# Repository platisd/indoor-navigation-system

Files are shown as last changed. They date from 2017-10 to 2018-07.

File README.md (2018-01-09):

# Indoor Navigation System  

[WIP] An indoor navigation system that guides you to the desk of your colleagues.

## What?
INS is a navigation system that utilizes a fleet of portable embedded devices, which can be located, to guide its user towards the desk of an employee or a colleague. The main scenario begins by searching for an employee on a mobile client. Then the system provides information regarding the whereabouts of the said employee's desk as well as navigational instructions on how to reach it.

The system does not intend to monitor individuals, but merely broadcast their currently designated workspace. The tracking nodes are not meant to be constantly carried along, but placed on the desk where someone is working on and forgotten until their owner changes desk.

## Why?
Medium and large organizations involve office settings where employees are spread out throughout different floors. It is typically difficult to locate personnel with whom there is infrequent physical collaboration. The challenge becomes even greater when employees either do not possess a dedicated work-area or tend to move between locations. The main advantage of INS is that it provides dynamic updates in case the position of an employee's workspace changes, voiding the need for any manual action from  the employee's side.

What is possibly more important is the technology developed within this context, can be easily reused in different occasions, such as in IoT and indoor positioning applications.

## How?
A fleet of portable devices, transmit the signal strength (RSSI) of their surrounding WiFi access points (AP) to a central server. Since the exact location of the various APs is known, we can utilize the provided data to pinpoint the nodes within the building. Finally, a user can fetch the calculated location from the server using a mobile client.

INS is a distributed system composed of the following layers that communicate via HTTP requests:
* [Node](/ins-node)
  * A portable device that transmits the signal strengths it detects. It is comprised of a WiFi Module that handles the connectivity and a Power Module that determines when the node should go to sleep to minimize its power consumption.
* [Server](/server)
  * A REST server that receives the RSSI signals, calculates the location of each node and supplies the information to the interested parties.
* [Client](/ins-app)
  * A mobile client that visualizes the location of the inquired employee and guides its user towards that location.

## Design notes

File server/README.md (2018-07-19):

# INS Server
The INS server provides a backend RESTful service for INS-node and front-end web or mobile applications.

## API
* Send RSSI value to INS server (INS node)

  INS-nodes are required to send RSSI readings per wifi AP's mac address to INS-service. In a bid to have accurate readings and handle outliers, the INS-server supports sending multiple data points from INS-nodes. A minimum of 1 data point and maximum of 10 data points can be sent in one http request, while unlimited number of requests can be used in sending readings.

  * HTTP Method - `POST`
  * Request Url -  `/set_rssi/:device_id/:mac_addr1/:rssi1/:mac_addr2?/:rssi2?/:mac_addr3?/:rssi3? ... /:mac_addr10?/:rssi10/?`
  * Response - `{result:success}` or `{result:error}`

    #### Examples
  * INS-node with device id 1000 sends a one-time RSSI reading for MAC addresses 23:43:3d:3e:5e:f5 and  5a:4e:44:ff:5a:6e.

    `http://localhost:9080/set_rssi/1000/23:43:3d:3e:5e:f5/12.323/5a:4e:44:ff:5a:6e/44.3434`

  * INS-node with device id 5239 sends multiple RSSI readings from MAC addresses 23:43:3d:3e:5e:f5, `5a:4e:44:ff:5a:6e with different requests at different times.

    `http://localhost:9080/set_rssi/5239/23:43:3d:3e:5e:f5/13/5a:4e:44:ff:5a:6e/40`
    `http://localhost:9080/set_rssi/5239/23:43:3d:3e:5e:f5/11.3/5a:4e:44:ff:5a:6e/44.3`
    `http://localhost:9080/set_rssi/5239/23:43:3d:3e:5e:f5/15.6/5a:4e:44:ff:5a:6e/44.4`

* Trigger position calculation for device.

  Since INS-service supports data submission in batches, calculation of the INS-node position from RSSI readings is only done when the device prompts the server.
  * HTTP Method - `POST`
  * Request url - `/resolve_pos/:device_id`
  * Response - `{result:success}` or `{result:error}`

    #### Example
  * INS-node with device id 5239 triggers device position computation after sending several RSSI readings.

    `http://localhost:9080/resolve_pos/5239`

* Clear stored RSSI data for a device.

  In a scenario when an INS-node is moved from one place to the other, it becomes needed to promt the server to clear all previously stored data readings which automatically becomes invalid due to the move.
  * HTTP Method - 'POST'
  * Request url - `/reset_pos/:device_id`
  * Response - `{result:success}` or `{result:error}`

    #### Example

  * INS-node with device id '3331' resets its position.

    `http://localhost:5300/reset_pos/3331`

* Retrieve employee position (Frontend).

  This is for user facing applications interested in fetching employee's position.
  * HTTP Method - `GET`
  * Request Url - `/get_employee_pos/:employee_id`
  * Response - `{employee_id:<id>, pos_x:<val>, pos_y:<val>, pos_z:<val>}`

    #### Example
  * Get position of employee with id = 8923

    `http://localhost:5300/get_employee_pos/8923`

* Retrieve device position (Frontend).

  This is for user facing applications interested in fetching position of an INS-node devicce.
  * HTTP Method - `GET`
  * Request Url - `/get_device_pos/:device_id`
  * Response - `{device_id:<id>, pos_x:<val>, pos_y:<val>, pos_z:<val>}`

    #### Example

  * Get position of device with id = 2020

    `http://localhost:5300/get_device_pos/2020`

## Dependencies
* [Pistache](http://pistache.io/)
* [Sqlite3](https://www.sqlite.org/)
* [spdlog](https://github.com/gabime/spdlog)

### How To Fetch Dependencies
#### Ubuntu
* Install SQLite3
    * `sudo apt-get install sqlite3 libsqlite3-dev -y`
* Install Pistache
    * `git clone https://github.com/oktal/pistache.git`
    * `cd pistache`
    * `mkdir build && cd build`
    * `cmake -G "Unix Makefiles" -DCMAKE_BUILD_TYPE=Release ..`
    * `make`
    * `sudo make install`

## Build & Run Backend Server
Ensure all needed libraries are installed.
* `cd server`
* `mkdir build`
* `cd build`
* `cmake ..`
* `make`
* To run use `./ins_server [port]`

## Testing
This component is tested using [GoogleTest](https://github.com/google/googletest/tree/master/googletest) and [GoogleMock](https://github.com/google/googletest/tree/master/googlemock) which are C++ testing and mocking frameworks.

The repository contains a [include/](include/) and [src/](src/) directories where the user is expected to maintain their production code and the [test/](test/) directory where the respective unit test and mocks have to be placed.

### How to run tests
* Build and run unit tests
  * `build_and_run_ut.sh`
* Build and run unit tests, cleaning the build folder
  * `build_and_run_ut.sh --clean`

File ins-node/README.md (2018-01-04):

# INS-node
The INS-node is the device that will allow us to pinpoint the location of our colleagues' desks.

## Setup your IDE
Follow the instructions found [here](https://wiki.wemos.cc/tutorials:get_started:get_started_in_arduino#using_git_version) to setup your Arduino IDE and enable it to compile and upload sketches for Wemos Mini D1.

To be able to compile for the ATtiny, please follow the instructions [here](https://github.com/SpenceKonde/ATTinyCore/blob/master/Installation.md).

## Power Controller :left_right_arrow: WiFi Module interaction
The Power Controller MCU is in charge of managing when the WiFi module is to be turned on. That being said, the WiFi module occasionally has some saying on what needs to be done.

There are two signals connecting the two components which additionally happen to be UART-capable. On the Power Controller these are `PB0` as `TX` and `PB1` as RX. On the WiFi module the standard `RX` and `TX` pins are utilized. Currently the two modules interact through sending signals as short (few microseconds) pulses.

The following table describes the protocol in the different states.

| Power Controller state | Source | Destination | Description |
| :----:|:----:|:----:|:----:|
| `SLEEP_WIFI_ON` | Power Controller | WiFi Module  | Notifies WiFi Module to shutdown, transits to `PREPARE_SHUTDOWN` state where it will turn off after `WIFI_PREPARE_SHUTDOWN_DURATION`. |
| `SLEEP_WIFI_ON` |  WiFi Module | Power Controller | Notifies Power Controller that it wants to shutdown and Power Controller transits to `PREPARE_SHUTDOWN` state where it will turn off after `WIFI_PREPARE_SHUTDOWN_DURATION`. |
| `PREPARE_SHUTDOWN` |  WiFi Module | Power Controller | Notifies Power Controller to prevent shutdown and go back to `SLEEP_WIFI_ON` state. |

## Testing
To test the INS-node code we base our work on the [Smartcar-gmock](https://github.com/platisd/smartcar-gmock) framework.

It is based on [GoogleTest](https://github.com/google/googletest/tree/master/googletest) and [GoogleMock](https://github.com/google/googletest/tree/master/googlemock) which are some easy-to-use C++ testing and mocking frameworks. It builds upon the [Arduino-Mock](https://github.com/ikeyasu/arduino-mock) project by Anders Arnholm and Yasuki Ikeuchi.

The repository contains a [src/](src/) directory where the user is expected to maintain their production code and the [test/ut/](test/ut/) directory where the respective unit tests (\*.cc files) have to be placed.

The main challenge with testing this is that the Arduino library was not created with testability in mind. There are already plenty of mocks, however they are not enough to cover the whole API. In case more mocks **need** to be added, we can use our local [fork](https://github.com/platisd/arduino-mock) to do so. Alternatively, functions, registers and variables should be stubbed when their mocking is not crucial for the testing process.

### How to run tests
* Build and run unit tests
  * `build_and_run_ut.sh`
* Build and run unit tests, cleaning the build folder
  * `build_and_run_ut.sh --clean`

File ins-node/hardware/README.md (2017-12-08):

# INS-node hardware
INS-node board schematics and layout designed with Eagle CAD.

## Features
* UART connection between power controller MCU and WiFi module
* N-channel MOSFETs to control the power
* 1 LED for power controller MCU
* 1 LED for WiFi module
* Decoupling capacitors
* Reset button for power controller MCU
* Drawing area for node id
* Mounting holes for M3 screws

## 2D board renders
* Top view

ins board TOP
* Bottom view

ins board BOTTOM

## List of materials
* Wemos D1 Mini
* ATtiny85
* 3 x AAA battery holders
* 2 x 2N7000 N-channel MOSFET
* 2 x 220 Ohm resistors
* 2 x 4.7 KOhm resistors
* 0.1 uF capacitor
* 2 x 5mm LED
* SPST tactile switch

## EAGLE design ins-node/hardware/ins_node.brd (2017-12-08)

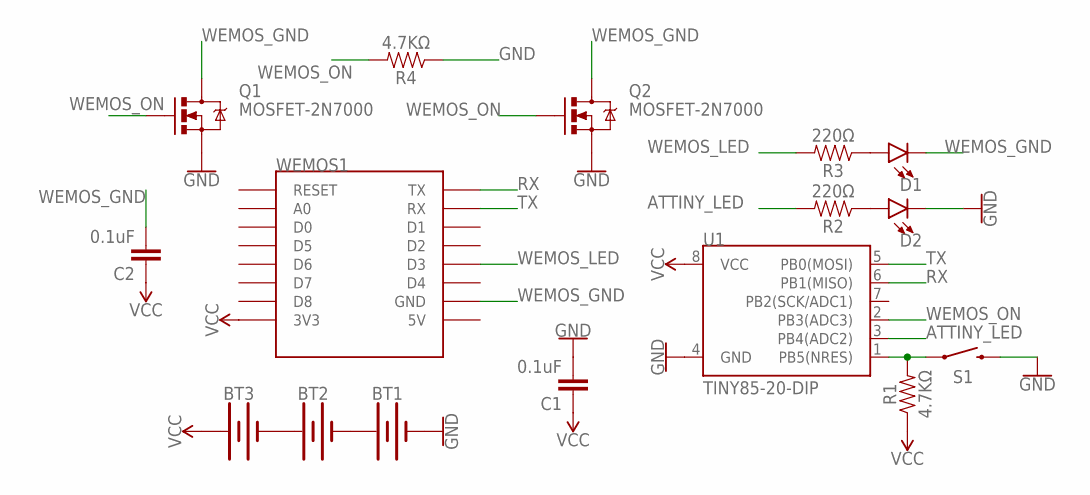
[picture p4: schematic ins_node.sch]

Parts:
BT1, BT2, BT3: BATTERY-AAA
C1, C2: 0.1uF; CAP-PTH-SMALL-KIT
D1, D2: LED5MM-KIT; LED_5MM-KIT
Q1, Q2: MOSFET-2N7000; TO-92
R1, R4: 4.7KΩ; AXIAL-0.3
R2, R3: 220Ω; AXIAL-0.3
S1: MOMENTARY-SWITCH-SPST-PTH-6.0MM; TACTILE_SWITCH_PTH_6.0MM
U1: TINY85-20-DIP; DIP08_MCU
WEMOS1: WEMOS-D1-MINI

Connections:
ATTINY_LED: R2.P$2 (2), U1.3 (PB4(ADC2))
GND: BT1.GND@1 (-), C1.2, D2.K (C), Q1.1 (S), Q2.1 (S), R4.P$1 (1), S1.3 (2), U1.4 (GND)
unnamed: BT1.PWR@1 (+), BT2.GND@1 (-)
unnamed: R1.P$2 (2), S1.1, U1.1 (PB5(NRES))
unnamed: D1.A, R3.P$1 (1)
unnamed: D2.A, R2.P$1 (1)
unnamed: BT2.PWR@1 (+), BT3.GND@1 (-)
RX: U1.6 (PB1(MISO)), WEMOS1.TX
TX: U1.5 (PB0(MOSI)), WEMOS1.RX
VCC: BT3.PWR@1 (+), C1.1, C2.1, R1.P$1 (1), U1.8 (VCC), WEMOS1.3V3
WEMOS_GND: C2.2, D1.K (C), Q1.3 (D), Q2.3 (D), WEMOS1.GND
WEMOS_LED: R3.P$2 (2), WEMOS1.D3
WEMOS_ON: Q1.2 (G), Q2.2 (G), R4.P$2 (2), U1.2 (PB3(ADC3))

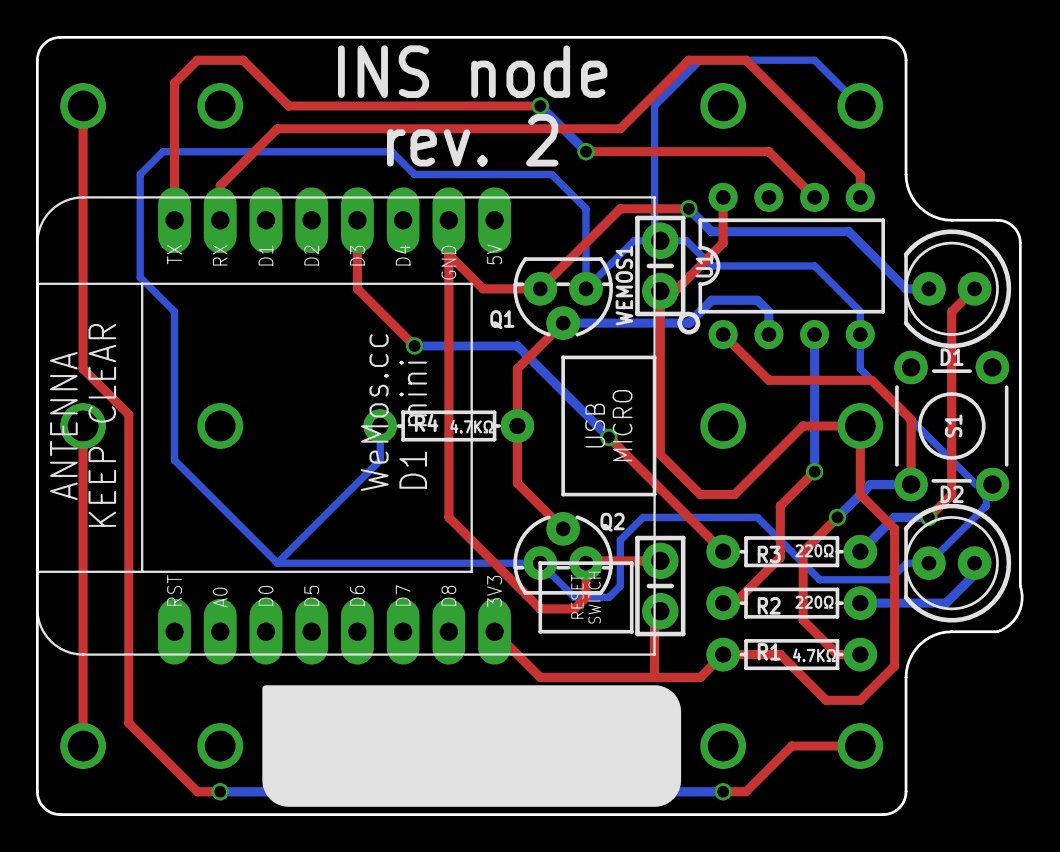
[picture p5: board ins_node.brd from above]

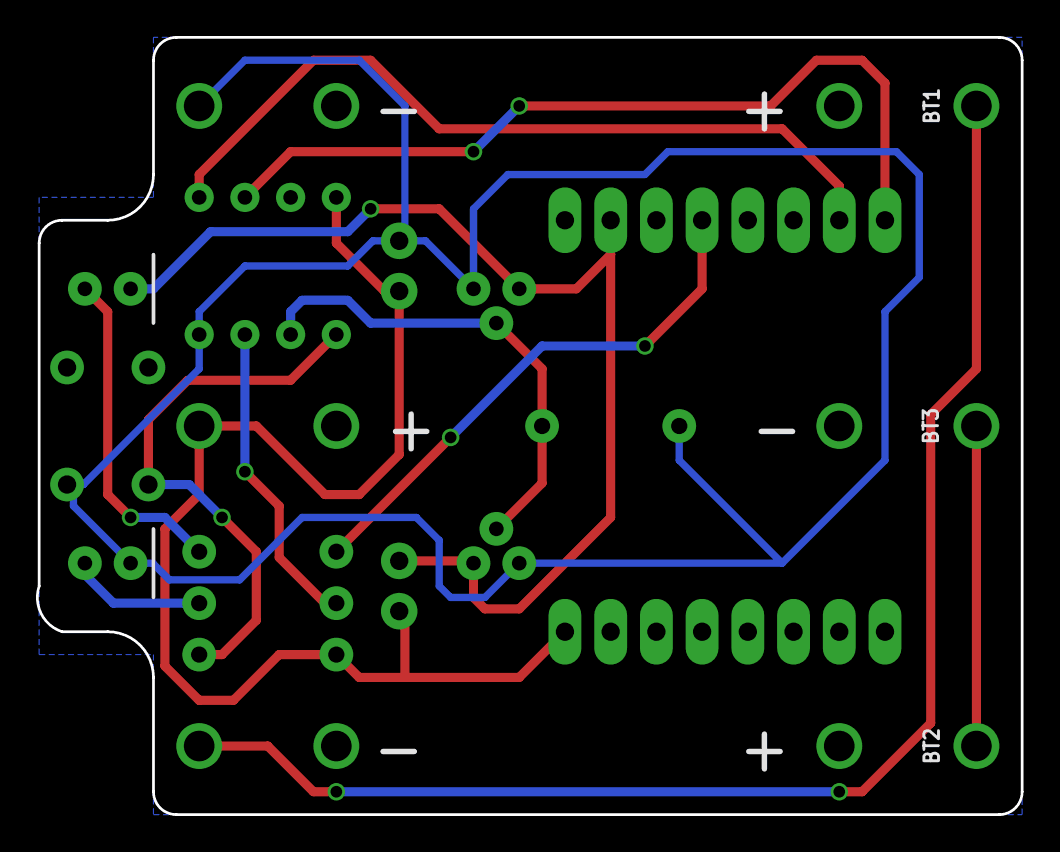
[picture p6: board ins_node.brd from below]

Board: 2 copper layers, 54.7 x 43.2 mm, 16 parts (3 on the bottom side), 13 nets.

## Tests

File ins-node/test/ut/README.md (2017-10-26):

## Unit test code directory
Place your unit tests, that you want to test and/or run on the INS node here as *.cc files.

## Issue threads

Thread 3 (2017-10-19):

Missing CI

platisd, 2017-10-19:
As a developer or tester, I would like the project to be built and the test cases to be ran after every commit so to figure out if my changes are making the system fail.

DoD:
* Decide on which CI (e.g. [Travis](https://travis-ci.org/))  is most suitable.
* Set up CI machinery that will build the current components (if possible) after every commit.
* Provide access to the CI machinery to rest of the project members.

Closed 2017-10-19.

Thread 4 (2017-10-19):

Backend Impl - REST Server

platisd, 2017-10-19:
As a developer, I would like to have REST server that can handle HTTP POST/GET requests, so that devices & frontend app can communicate with the server.

platisd, 2017-10-19:
Is this done @samup4web ?

samup4web, 2017-10-19:
This issue and the database impl issue are somehow in the same boat. More work to be done as new related tasks unfolds.

samup4web, 2017-10-20:
Fixed in [commit](https://github.com/platisd/indoor-navigation-system/commit/8e1333d574c81e35b327888606187d7dc6828c4e)

Closed 2017-10-20.

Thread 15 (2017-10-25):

Missing test infrastructure - server

platisd, 2017-10-25:
As a CI machine I would like to be able to have the infrastructure in place which will enable me to run unit tests.

DoD:
* `run_ut.sh` script inside `server` directory which builds and runs a sample unit test.

platisd, 2017-11-01:
This is done right? If so, move it to "Ready for internal acceptance" in the project board! :)

Closed 2017-10-29.

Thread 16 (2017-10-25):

Missing test infrastructure - ins-node

platisd, 2017-10-25:
As a CI machine I would like to be able to have the infrastructure in place which will enable me to run unit tests.

DoD:
* `build_and_run_ut.sh` script inside `ins-node` directory which builds and runs a sample unit test.

Protip:
* Follow [smartcar-gmock](https://github.com/platisd/smartcar-gmock) structure for testing and mocking arduino.

samup4web, 2017-10-27:
So, after preparing my commit for test infrastructure for the server. I saw [this](https://github.com/platisd/indoor-navigation-system/blob/323b52b1a12611e5bdb707e32dee58535e1602ca/ins-node/test/arduino_mock/CMakeLists.txt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) in your commit. That is super new to me. I guess I wouldn't need a copy of gtest/gmock with your approach. I will fix the feature branch before making a pull request. Cheers!

platisd, 2017-10-27:
You don't really *have* to follow that approach, but if you think it makes sense sure, go for it! :+1:  :smiley:

samup4web, 2017-10-27:
Yeah, I think it's a cool approach 😄

Closed 2017-10-26.

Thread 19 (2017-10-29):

Missing hardware prototype

platisd, 2017-10-29:
As an INS-node I want become materialized so to stop being a figment of imagination and speculation.

DoD:
* Board layout and schematics designed in [Eagle CAD](https://www.autodesk.com/products/eagle/overview)
* ~~[Fritzing](http://fritzing.org/home/) diagram added in [README.md](https://github.com/platisd/indoor-navigation-system/blob/master/ins-node/README.md)~~

platisd, 2017-10-29:
@samup4web @lexious89 I was thinking about the optimum hardware setup for the beginning and concluded on a [Wemos D1 Mini](https://wiki.wemos.cc/products:d1:d1_mini), **instead** of an [ESP-01](https://4tronix.co.uk/store/resources/image/18/c2/2.jpg), Attiny25 (or 85) combo. This means that the total architecture will change a little bit as to where the main business logic is contained.

According to the old setup:
* ESP-01 was operated in AT-mode, meaning that we send commands to it via UART.
* Attiny parses the results and handles power management.

According to the new setup:
* We program the ESP8266 on the Wemos D1 Mini directly.
* Attiny handles power management.

Advantages :vs: disadvantages of the new approach:
* Easier and faster to develop/modify the main business logic since the Wemos can be programmed over USB with the Arduino IDE. :white_check_mark:
* Can practically use any other ESP8266 USB development module like the one @lexious89 has. :white_check_mark:
* Slightly more expensive. (ESP-01 costs ~1.6$ while Wemos D1 Mini costs ~2.6$) :x:
* Slightly larger. :white_check_mark:
* Faster and more versatile setup since we do not rely on already made AT-commands to access the ESP8266 but we program it directly. :white_check_mark:
* Simpler and fewer hardware connections on the PCB from our side, meaning less risk. :white_check_mark:

Does it sound good? :smiley:

PS. Also thinking of a knowledge sharing workshop on PCB design where I can go over how to design the board if you are interested in it!

samup4web, 2017-10-29:
Sounds like a good idea. I guess the cost impact is quite marginal, and for the size, as long as we can package it in something nice then I see no problem.

The PCB design knowledge sharing is a great idea!.

platisd, 2017-10-29:
I have scratched out the creation of a Fritzing diagram as it will be redundant work at this point.

Closed 2017-10-30.

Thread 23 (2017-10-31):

Missing initial implementation of power controller

platisd, 2017-10-31:
As an INS node, I would like my power controller to turn off the Wifi module when it is not needed and stay in deep sleep as much as possible so to preserve precious battery life.

DoD:
* Wifi module gets turned on every ~1 minute.
* MCU stays in deep sleep as much as possible.
* State machine with (at least) the following states:
  * `SLEEP_WIFI_OFF` (the wifi module is off, while power controller is in deep sleep and can be woken up by a watchdog timer)
  * `SLEEP_WIFI_ON` (the wifi module is on, while power controller is in deep sleep and can be woken up by a watchdog timer or an external interrupt).
  * `PREPARE_SHUTDOWN` (the power controller warns the Wifi module it is time to shutdown and then it goes to deep sleep for a limited period. The Wifi module can ask to postpone shutdown if it is not ready to)

Closed 2017-11-17.

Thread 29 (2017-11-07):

Apply corrections to rev. 0 board

platisd, 2017-11-07:
As an INS I want to work as intended by my creators so to make them happy.

**HW rev. 0** has the following problems:
* Batteries slightly too close to the WiFi Module, should be moved couple of millimeters to the sides.
* Understand why WiFi module receives too low voltage and implement a solution.

DoD:
Above problems are fixed and new boards are ordered.

platisd, 2017-11-09:
These are my current findings in regards to this problem:
* I could not get the Wemos D1 mini to power up directly from 2 AAA batteries (or the equivalent voltage) in any consistent nor reliable manner. I could however get it to power up **directly** from **3 batteries** connected to the 5V pin or the 3.3V pin.
* Using **two** 2N7000 MOSFETs to handle the current (it won't work with just the one we currently have!) I was able to power it up reliably with voltages from 4.0V to 4.5V connected to the 3.3V pin. This is probably not a very good idea, but seems to work. Now whether this will destroy the ESP chip at some point is a different question. :stuck_out_tongue:
* Two MOSFETs will be also able to drive 5V to the 5V pin and power the WeMos up reliably.
* Three MOSFETs were also able to drive the Wemos with 4.5V connected to the 5V pin. However there seemed to be problems when I lowered the voltage to around 4V.
* I was reading contradicting reviews on the Wemos power consumption while in deep sleep (i.e. in the occasion we'd decide not to use a power controller chip). Some were very optimistic (e.g. 150uA in deep sleep which would allow the batteries to last for at least a couple of months) while others gave a pretty bad picture (e.g. 20mA). I did not have time to make my own experiments, so this might worth investigating more.

So, overall there seem to be various options available on how to power the WeMoS up. The overall problem is choosing the appropriate power source at a voltage that is as close to the specs as possible AND at the same time will keep being able to power the WeMos even if the voltage falls as time passes (and also cheap).

My best suggestion is 3 AAA batteries wired up to the 3.3V pin driven by 2 2N7000 MOSFETs. At full battery power, the voltage that actually reaches the chip is 4V. According to the specs, the maximum voltage is 3.6 voltage. We seem to be over it by 0.4V in other words, but since it seems to work and the plan is to keep the Wemos turned off for most of the time, I suggest that we go for that. It is a risk, but I honestly cannot think of a better solution that will not cost us a lot and will have other problems (I am looking at you Lithum batteries).

Let's make a decision tomorrow and order the new boards by tomorrow night!

Closed 2017-11-13.

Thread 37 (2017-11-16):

Have the CI build the ins-node firmware (Power Controller)

platisd, 2017-11-16:
As a developer or an integrator I want to be certain that what I wrote will compile in all setups so to avoid having non-working software committed even though the until tests passed.

DoD:
* The CI machine compiles the firmware for the appropriate microcontroller before/after running the unit tests.

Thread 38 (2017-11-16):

Have the CI build the Wifi Module firmware

platisd, 2017-11-16:
As a developer or an integrator I want to be certain that what I wrote will compile in all setups so to avoid having non-working software committed even though the until tests passed.

DoD:
* The CI machine compiles the firmware for the appropriate microcontroller before/after running the unit tests.

platisd, 2018-01-03:
Building the firmware for the ESP8266 as well as the power controller (see #37) seems to require downloading the Arduino IDE as well as the necessary additional libraries and SDKs. This will make the whole build much slower, especially in the case of the ESP8266.

Currently, the build is a bit over 20 minutes so we should consider whether we want these builds to take place.

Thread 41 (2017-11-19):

Determine the cause of Wemos external LED malfunction

platisd, 2017-11-19:
The LED connected to the WiFi module is misbehaving (i.e is constantly turned on) regardless of the WiFi Module's pin output.

DoD:
* Determine the cause of this defect (it is hardware/electrical related)
* Apply corrective action (removing the LED completely is not a bad option)

platisd, 2017-12-05:
This is probably related to #65

platisd, 2017-12-22:
I am almost sure the problem stems from the fact that we are using software for a newer hardware version (i.e. R2 and R3) than we actually have (R1). It looks like the mapping of Arduino pin numbers to ESP8266 pins has changed between the versions! For example, for R1 hardware, pin D4 in code is actually D2 on the board!

I shall investigate this further soon to determine the cause of this defect with greater certainty, regardless of whether we maintain the specific LED on the board or not.

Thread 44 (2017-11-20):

Wifi module gets a list of RSSI values from different AP's for specified SSID

platisd, 2017-11-20:
As a WiFi module I want to be able to retrieve the RSSI values from the surrounding AP's of a specified SSID so to be able to send them to the server.

DoD:
* The WiFi module is able to fetch the SSID's of a specified SSID.
  * To verify this they can be printed out for the time being.
* Unit tests that cover the new functionality.
  * A lot of mocking probably has to be done. Keep in mind that the current mocks don't cover Arduino's `String` class type.

platisd, 2017-11-20:
@lexious89 can you please add the relevant code you had demonstrated for us?

Closed 2017-12-05.

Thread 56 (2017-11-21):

Stabilize pseudo random rssi levels by filtering out shadowing and multipath noise.

lexious89, 2017-11-21:
## Description
Due to random effects in the environment, rssi levels taken even within small intervals appear random and noisy. In order to compute a stable position, we need to filter out the randomness due to shadowing and mulitath and only have just path loss. One way to do this is for eg: moving averaging.
## Definition of Done
Compute a single value that represents the signal level at a single position.

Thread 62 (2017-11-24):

Refactor: Change RSSI datatype

samup4web, 2017-11-24:
## Description
Since it is confirmed that `rssi` representation is indeed `int32_t` [(link),](https://github.com/esp8266/Arduino/blob/d7044eceab4d4453e4d73ac49dcbbc8b8d0c9eb1/doc/esp8266wifi/scan-class.rst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) as a developer, I want the correct datatype used for all `rssi` variables.

## Definition of Done
Correct datatype is used for RSSI variables.

Closed 2017-12-05.

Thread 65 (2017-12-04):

PB0 (TX) pin emits negative voltage

platisd, 2017-12-04:
## Description
PB0 has been measured to emit negative voltage (when it should be steadily at 0V with the current firmware) which results in a weird ~1.0V value being supplied at the wifi module even when it is off.

A workaround for this is to bend (not connect) the RX pin of the WiFi module.

## Definition of Done
Root cause of this strange behavior is identified and a fix is issued.

Closed 2017-12-08.

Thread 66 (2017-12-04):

Wrong pin used for turning Wifi module ON

platisd, 2017-12-04:
## Description
The power controller uses the PB2 for turning the WiFi module ON, while according to the schematics the PB3 pin should be used instead.

## Definition of Done
PB3 pin is used to turn the WiFi module on in the power controller firmware.

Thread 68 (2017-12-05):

Server core-dumps after ~16 minutes of operation

platisd, 2017-12-05:
## Description
The `ins_server` core-dumps after approximately 16 minutes of operation, regardless of whether it is handling incoming data or not. The defect was reproducible 100% of the times.

### Ways to reproduce
Have `ins_server` executing for long amounts of time.

### Related logs
> terminate called after throwing an instance of 'std::runtime_error'
>   what():  No route to host
> Aborted (core dumped)

## Definition of Done
The `ins_server` can run for indefinite amounts of time.

samup4web, 2017-12-05:
@platisd hmm, what is your setup like?
I tried running the ins_server on my machine and it runs for over 1 hour, and also accepted request thereafter. See the time-stamp prints in the screenshot below.
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

I will investigate further...

samup4web, 2017-12-05:
I still have the server running, I will see how long before I reproduce the problem.

platisd, 2017-12-05:
How did it go? Otherwise it must be some local weird error, since I could consistently reproduce it.

samup4web, 2017-12-05:
Still running at 19:38 ...

platisd, 2017-12-05:
Weird... Let's close this for now and I will open it again if I have a different angle on it.

samup4web, 2017-12-05:
@lexious89 can you try to run the server on your box and let's see if you can reproduce the problem.

samup4web, 2017-12-09:
I manage to reproduce this issue. I will be investigating further...

platisd, 2017-12-09:
Interesting, keep us posted! :+1:

samup4web, 2017-12-09:
Strangely enough, I am on my second attempt to reproduce the problem after the first crash with no success. Will be testing on both my ubuntu box and rasberrypi.

samup4web, 2017-12-09:
On a side note, @platisd are you on slack?

platisd, 2017-12-09:
I sure am! 😛

Send invite to my work mail if you're making a channel

samup4web, 2017-12-09:
Done.

samup4web, 2017-12-09:
OK, couldn't get it to crash. So, am making a new run on rasberrypi now.
* ins service start time - [2017-12-09 17:36:55.200]
* ins_node start time - [2017-12-09 18:16:52.178]
* current time - [2017-12-09 18:35:01.948]
This will be running all night, so fingers crossed.

platisd, 2017-12-09:
What is your setup like? Are you using the wifi_module.ino without letting it sleep?

samup4web, 2017-12-09:
Yes, modified wifi_module to not sleep and send data continuously with `delay(20000);`.

samup4web, 2017-12-10:
Strange that INS service has been running all night/day and still running (on rasberrypi)
* current time - `[2017-12-10 14:01:14.282]`

I had to press reset button on ins_node this morning because it wasn't sending out data. I guess due to network connection.

platisd, 2017-12-10:
I will also try to debug this when I find the time. Any suggestions on where to add extra logs?

samup4web, 2017-12-10:
Okay, great! As for extra logs, none that I can think of now.

samup4web, 2018-01-20:
Closing this issue since we haven't observed this issue lately. This can be re-opened again if problem reoccur

platisd, 2018-01-20:
I agree. That being said, I think it could make sense to invest in making a Docker image to make sure everyone is running things in the same environment. :+1:

samup4web, 2018-01-20:
Haha, nice idea. Taking it to another level :smile_cat:

Closed 2018-01-20.

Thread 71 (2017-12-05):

Add pull down resistors to MOSFETs so to ensure a clean trigger signal

platisd, 2017-12-05:
## Description
As a Wifi module I want to be turned on only when the Power Controller sees it fit and not accidentally by rogue static voltages applied on the trigger pins of the MOSFETs.

## Definition of Done
* Pull down resistor added
* BOM updated
* Board renders updated

Closed 2017-12-08.

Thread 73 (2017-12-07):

Android application setup missing

platisd, 2017-12-07:
## Description
As an INS Android app developer I want to have a sample Hello World application integrated into the CI build and tested, so to be able to seamlessly create awesome things with it.

## Definition of Done
* Hello World android application
* Built and tested by the CI machine
* Coverage reports on codecov.

Closed 2017-12-30.

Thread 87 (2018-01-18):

INS node position resolution missing

platisd, 2018-01-18:
## Description
As an INS node I should instruct the server to resolve my position after I am done transmitting the RSSI values. On how to do that, please refer to `Trigger position calculation for device` section of the [server/README.md](https://github.com/platisd/indoor-navigation-system/blob/dev/server/README.md).

## Definition of Done
* The `ins-node` [WiFi module](https://github.com/platisd/indoor-navigation-system/blob/dev/ins-node/src/wifi_module/wifi_module.ino) is able to trigger the position resolution interface of the server after successfully transmitting a batch of data.
* The added functionality is tested.

lexious89, 2018-04-13:
+ and in addition ask the server to resolve position some fixed period (say every minute) even if the device node does not request it.

platisd, 2018-04-13:
Do you mean to have a timer on the server? I think it's supposed to be stateless. What do you think @samup4web

lexious89, 2018-04-13:
Yes, it is stateless in relation to the ins nodes. But the server knows how long it has been running.
This is needed because if it is the first time the insnode is transmitting data and it happens to loose connection or something goes wrong so that the location table in ins_db is empty for that device, any front end get-position request will yield unpredictable results - a nan in the localization process, whilst in fact the data is available for localization.

platisd, 2018-04-13:
Sounds good to me

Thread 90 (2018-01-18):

C++ code has been committed without being static analyzed

platisd, 2018-01-18:
## Description
As an INS developer I do not want to have code that has not been approved by a static analysis tool committed to one of the main branches. Therefore, I would like to make sure that my code is verified by a static analysis tool before being allowed to merge.

A good relevant post to read can be found [here](https://legalizeadulthood.wordpress.com/2014/12/07/adding-static-analysis-to-your-c-github-repository/).

## Definition of Done
* A static analysis tool (e.g. `cppcheck`) is run by Travis and verifies the submitted code before allowing to merge
* Static analysis script is present in the c++ source folders, e.g. `server/run_static_analysis.sh`
* Current problems, discovered by static analysis tool, are addressed
* (Optional) Try to run the static analysis check in parallel with the rest of the build

samup4web, 2018-01-20:
Clang-tidy :+1:

platisd, 2018-01-20:
Up to the one who implements this! :smiley:

platisd, 2018-01-22:
@samup4web are you currently working on this? If so please move this to the appropriate column in the board otherwise unassign yourself so maybe new members can take it! 😄

samup4web, 2018-01-22:
Yes working on this, forgot to move it status.

lexious89, 2018-04-23:
Is this issue solved? @samup4web

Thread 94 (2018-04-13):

Create patch case to adapt project to a specific case

lexious89, 2018-04-13:
## Description
As the project is intended for indoor settings, different cases will require special configurations, graphics and resources in local config etc. You can either do this in code or by patching before building.
We want to create a simple patch for a specific case that anyone can modify to suite their own application.
## Definition of Done
Fulfill the above requirement by providing a patch script in the repository.

platisd, 2018-04-13:
Can you be more specific on what needs to be done? If I were to take up this story I wouldn't know what to do or where to start!

platisd, 2018-04-14:
I was thinking of this and I believe that you mean that we should refactor this so to be a platform and be able to satisfy different use cases. Right now the "platform" (i.e. purpose agnostic hardware and software) are tightly coupled with the "indoor navigation" use case.

I do agree that this should happen but it's a rather large task that should be broken down further and possibly some architectural changes should ensue!

lexious89, 2018-04-16:
Yes, I agree the description is quiet vague. I have updated the contents above. The platform is indeed for indoor cases alone. But different indoor settings will employ different wifi APs (mac address, rssi levels etc), and indoor maps, perhaps in the future, various ins node hw/sw-revisions. We can't anticipate all use cases. But it would be really helpful to be able to run a script to swap between various use cases (platform) and a generic patch script might be enough. This is what I meant.
I guess we could break it down into smaller series of tasks.

platisd, 2018-04-16:
OK I understand better now but still think it needs smaller tasks as well as some architectural discussion. The main problem is that some of the infrastructure and prerequisites for this are missing.

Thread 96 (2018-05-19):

Read and transmit temperature readings along with the RSSI data

platisd, 2018-05-19:
## Description
As an facilities manager I want to be able to see what is the temperature around each INS-node so to be able to adjust the heating or cooling accordingly.

## Definition of Done
* A readily available, cheap and small temperature sensor is selected
* The INS-node is able to measure the temperature
* The INS-node is able to transmit the measured temperature along with the RSSI readings

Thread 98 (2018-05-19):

INS app to fetch temperature data and visualize them

platisd, 2018-05-19:
## Description
As an facilities manager I want to be able to see what is the temperature around each INS-node so to be able to adjust the heating or cooling accordingly.

## Definition of Done
* INS app to fetch the temperature data for each node id from the server.
  * The POST request should be formulated as `http://localhost:9080/get_temperature/id` where `id` is an arbitrary identification number (integer) until #82 is implemented.
* The temperature is visualized with different colors over a map of the floor.
* Documentation is updated accordingly (if applicable).

platisd, 2018-05-19:
@Dionysios it goes without saying that you should feel free to add more details to this issue, as long as the scope doesn't stretch "too much" :stuck_out_tongue: .

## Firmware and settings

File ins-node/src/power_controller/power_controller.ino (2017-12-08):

#include <stdint.h>
#include <avr/sleep.h>
#include <avr/power.h>
#include <avr/wdt.h>
#include <avr/interrupt.h>

enum WatchDogTimeout {
  WDT_16ms = 0,
  WDT_32ms,
  WDT_64ms,
  WDT_128ms,
  WDT_250ms,
  WDT_500ms,
  WDT_1sec,
  WDT_2sec,
  WDT_4sec,
  WDT_8sec
};

enum PowerState {
  // The wifi module is off, while power controller is
  // in deep sleep and can be woken up by a watchdog timer.
  SLEEP_WIFI_OFF,
  // The wifi module is on, while power controller is in
  // deep sleep and can be woken up by a watchdog timer
  // or an external interrupt.
  SLEEP_WIFI_ON,
  // The power controller warns the Wifi module it is time
  // to shutdown and then it goes to deep sleep for a
  // limited period. The Wifi module can ask to postpone
  // shutdown if it is not ready yet.
  PREPARE_SHUTDOWN
};

const uint8_t TX_PIN = PB0;
const uint8_t RX_PIN = PB1;
const uint8_t WIFI_MODULE_PIN = PB3; // Controls the power to the Wifi module

WatchDogTimeout currentTimeout = WDT_8sec; // Current watchdog timeout

unsigned long timeWeHaveSlept = 0; // The total amount of time we have been asleep
volatile bool watchDogBarked = false; // Flag to determine the source of a wake up
bool watchDogEnabled = false;

const unsigned long WIFI_OFF_SLEEP_DURATION = 16000UL; // TO-DO: Change this to something larger
const unsigned long WIFI_ON_SLEEP_DURATION = 16000UL; // TO-DO: Change this to something larger
const unsigned long WIFI_PREPARE_SHUTDOWN_DURATION = 10000UL;

volatile bool signalFromWifiModule = false; // Flag to determine if WiFi module has signaled us

PowerState currentState = SLEEP_WIFI_OFF; // Current operational state

/**
   Change interrupt routine (e.g. when WiFi module signals us)
*/
ISR (PCINT0_vect) {
  // Only consider interrupts from the defined source and during the proper state(s)
  if ((currentState == SLEEP_WIFI_ON) && (digitalRead(RX_PIN) == HIGH)) {
    signalFromWifiModule = true;
  }
}

/**
  Watchdog interrupt routine to be triggered when watchdog times out.
*/
ISR(WDT_vect) {
  watchDogBarked = true;
  wdt_disable(); // Disable watchdog so it does not get automatically retriggered
}

/**
    Sets up watchdog to be triggered (once) after the specified time
    @param wdt  the watchdog timeout duration
*/
void triggerWatchDogIn(WatchDogTimeout wdt) {
  // Adopted from InsideGadgets (www.insidegadgets.com)
  byte timeoutVal = wdt & 7;
  if (wdt > 7) {
    timeoutVal |= (1 << 5);
  }
  timeoutVal |= (1 << WDCE);

  MCUSR &= ~(1 << WDRF);
  WDTCR |= (1 << WDCE) | (1 << WDE); // Start timed sequence
  WDTCR = timeoutVal;
  WDTCR |= _BV(WDIE);
  wdt_reset();  // Pat the dog
  currentTimeout = wdt;
}

/**
   Sets the MCU into a deep sleep state until a change interrupt is triggered
*/
void goToSleep() {
  set_sleep_mode(SLEEP_MODE_PWR_DOWN);
  ADCSRA = 0; // Turn off ADC
  power_all_disable(); // Power off ADC, Timer 0 and 1, serial interface
  sleep_enable();
  sleep_cpu(); // Sleep here and wait for an interrupt or watchdog bark
  sleep_disable();
  power_all_enable(); // Power everything back on
}

/**
   Sets up pin change interrupt for RX
*/
void setupRXInterrupt() {
  PCMSK |= bit (PCINT1); // Want pin D1 (PB1)
  GIFR |= bit (PCIF); // Clear any outstanding interrupts
  GIMSK |= bit (PCIE); // Enable pin change interrupts
}

/**
   A utility method to derive a watchdog timeout's duration
   @return the amount of milliseconds corresponding to a watchdog timeout
*/
unsigned long getTimeoutDuration() {
  return 1 << (currentTimeout + 4);
}

/**
    Puts the MCU to deep sleep and uses a watchdog timeout to wake it up after
    the currently set timeout. Monitors how long it has remained asleep since the
    last time it signaled a wake up.
    @param  totalSleepDuration how long to sleep in milliseconds
    @return                    whether it has remained asleep enough
*/
bool stayAsleepFor(const unsigned long totalSleepDuration) {
  // If watchdog is not enabled, then we either just arrived from a different state
  // or from a watchdog bark. Therefore we need to set another watchdog timer.
  if (!watchDogEnabled) {
    // If watchdog is not enabled and we are in this state
    // then we should set it up.
    triggerWatchDogIn(currentTimeout);
    watchDogEnabled = false;
  }
  // Go to deep sleep until an interrupt or watchdog bark occurs
  goToSleep();
  // We might have gone out of sleep due to an interrupt so make sure that we
  // know what we are doing depending on who interrupted our sleep.
  if (watchDogBarked) {
    watchDogBarked = false;
    watchDogEnabled = false;
    timeWeHaveSlept += getTimeoutDuration(); // Log how much time we've been in this state
    // Check if it is time to signal a state change
    if (timeWeHaveSlept >= totalSleepDuration) {
      timeWeHaveSlept = 0;
      return true;
    }
  }
  return false;
}

/**
   Notify the WiFi module that it is time to shut down
*/
void notifyWifiShutdown() {
  // Send a short pulse
  pinMode(TX_PIN, OUTPUT);
  digitalWrite(TX_PIN, HIGH);
  delayMicroseconds(5);
  digitalWrite(TX_PIN, LOW);
  pinMode(TX_PIN, INPUT);
}

void setup() {
  // Setup I/O pins
  pinMode(RX_PIN, INPUT);
  pinMode(TX_PIN, INPUT); // Set it as an input to avoid strange parasitic voltages
  pinMode(WIFI_MODULE_PIN, OUTPUT);

  // Initialize the pin states
  digitalWrite(WIFI_MODULE_PIN, LOW);

  setupRXInterrupt();
}

void loop() {
  switch (currentState) {
    case SLEEP_WIFI_OFF:
      {
        bool timeToChangeState = stayAsleepFor(WIFI_OFF_SLEEP_DURATION);
        if (timeToChangeState) {
          currentState = SLEEP_WIFI_ON;
          digitalWrite(WIFI_MODULE_PIN, HIGH); // Turn WiFi module on
        }
        break;
      }
    case SLEEP_WIFI_ON:
      {
        bool timeToChangeState = stayAsleepFor(WIFI_ON_SLEEP_DURATION);
        if (timeToChangeState || signalFromWifiModule) {
          currentState = PREPARE_SHUTDOWN;
          notifyWifiShutdown();

          signalFromWifiModule = false;
          timeWeHaveSlept = 0; // Reset this in case sleep was prematurely halted by an interrupt
        }
        break;
      }
    case PREPARE_SHUTDOWN:
      {
        bool timeToChangeState = stayAsleepFor(WIFI_PREPARE_SHUTDOWN_DURATION);
        // Since the timeout and the interrupt have different results we must
        // guard the sensitive area.
        noInterrupts();
        if (timeToChangeState) {
          currentState = SLEEP_WIFI_OFF;
          digitalWrite(WIFI_MODULE_PIN, LOW); // Turn WiFi module off
        } else if (signalFromWifiModule) {
          currentState = SLEEP_WIFI_ON; // Give it more time before turnign off
          timeWeHaveSlept = 0; // Reset since sleep was halted by an interrupt
        }
        signalFromWifiModule = false;
        interrupts();
        break;
      }
    default:
      break;
  }
}

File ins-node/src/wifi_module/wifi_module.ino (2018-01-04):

#include <stdint.h>
#include <math.h>
#include <vector>
#include <utility>
#include <set>
#include <ESP8266WiFi.h>
#include "wifi_credentials.h"

ESP8266WiFiClass wifi;
EspClass espPower;
const uint8_t DEVICE_ID = 1; // The identification for the specific node
const int8_t CONNECTION_RETRIES = 20; // The maximum amount of wifi connection attempts
const uint8_t DEFAULT_TRANSMISSION_SIZE = 10;
uint8_t currentTransmissionSize = DEFAULT_TRANSMISSION_SIZE;

const uint8_t TX_PIN = 10;
const uint8_t RX_PIN = 9;

/**
   Gets the network context (i.e. MAC address and RSSI value) of the specified
   network item.
   @param networkItem The network item index of which to fetch the context
   @return            A tuple of (MAC address, RSSI)
*/
std::pair <String, int32_t> getNetworkContext(int8_t networkItem) {
  std::pair <String, int32_t> context (wifi.BSSIDstr(networkItem), wifi.RSSI(networkItem));
  return context;
}

/**
   Measures the RSSI values for the various access points of the specified SSID
   and returns them along the MAC address of the respective access point.
   @return  The MAC addresses with their respective RSSI values
*/
std::vector<std::pair <String, int32_t>> getDatapoints() {
  std::vector<std::pair <String, int32_t>> datapoints;
  // Scan the surrounding networks and get how many were found
  auto networksFound = wifi.scanNetworks();
  for (auto i = 0; i < networksFound; ++i) {
    // Check if some of the networks should be used for positioning
    bool validNetwork = positioningNetworks.find(wifi.SSID(i)) != positioningNetworks.end();
    if (validNetwork) {
      datapoints.push_back(getNetworkContext(i));
    }
  }

  return datapoints;
}

/**
   Transmits the supplied data (if present) to the server
   @param  datapoints The MAC addresses and the RSSI values we collected
   @return            Whether transmission succesfull
*/
bool transmitData(std::vector<std::pair <String, int32_t>> datapoints) {
  // TO-DO: Notify the server that we could not gather any datapoints for
  // corrective actions to be made before sleeping.
  if (datapoints.empty()) {
    return false;
  }
  // Establish a TCP connection to the server
  WiFiClient client;
  if (!client.connect(SERVER_IP, HTTP_PORT)) {
    return false;
  }

  // Compose a request for the server according to the agreed format:
  // /set_rssi/device_id/mac_addr1/rssi1/mac_addr2/ ... /mac_addr10/:rssi10/
  String request = "/set_rssi/";
  request += DEVICE_ID;
  request += "/";
  for (auto datapoint : datapoints) {
    // We don't put everything in the same expression since std::string
    // (used in testing) is not exactly the same as Arduino String. Therefore
    // we go with this way of concatinating the string which is compatible with
    // both implementations.
    request += datapoint.first; // The MAC address
    request += "/";
    request += datapoint.second; // The RSSI value
    request += "/";
  }

  // Send the TCP request to the rest server
  client.print("POST " + request + " HTTP/1.1\r\n" +
               "Host: " + SERVER_IP + "\r\n" +
               "Connection: close\r\n\r\n");

  // Verify whether the request timed out
  bool successfulRequest = true;
  const unsigned long TIMEOUT = millis() + 5000;
  while (client.available() == 0) {
    if (millis() > TIMEOUT) {
      successfulRequest = false;
      break;
    }
  }
  client.stop();
  return successfulRequest;
}

/**
   Puts the module into deep sleep and signals the power controller to
   turn its power off.
*/
void goToSleep() {
  digitalWrite(TX_PIN, HIGH);
  delayMicroseconds(10);
  digitalWrite(TX_PIN, LOW);
  espPower.deepSleep(60 * 1000000UL); // Will sleep forever unless wakeup pin connected to RST
}

void setup() {
  // Setup IO pins.
  pinMode(TX_PIN, OUTPUT);
  pinMode(RX_PIN, INPUT);
  digitalWrite(TX_PIN, LOW);

  // Set WiFi to station mode and disconnect from an AP
  // if it was previously connected.
  wifi.mode(WIFI_STA);
  wifi.disconnect();
  delay(100);

  // Try to connect to the internet.
  wifi.begin(internetSSID, password);
  auto attemptsLeft = CONNECTION_RETRIES;
  while ((wifi.status() != WL_CONNECTED) && (--attemptsLeft > 0)) {
    delay(500); // Wait a bit before retrying
  }
  // If there were problems during connection, go to deep sleep.
  if (attemptsLeft <= 0) {
    goToSleep();
  }
}

void loop() {
  // Discover the access points we are interested in to log down their
  // MAC addresses and RSSI values.
  auto datapoints = getDatapoints();

  // We need to split the data in groups of 10, as this is the maximum amount
  // we have agreed to send per transmission.
  uint8_t transmissions = ceil(datapoints.size() / static_cast<double>(currentTransmissionSize));
  for (auto i = 0; i < transmissions; i++) {
    // Get the next currentTransmissionSize elements as a new vector
    std::vector<std::pair<String, int32_t>> transmissionData(
                                           datapoints.begin() + (i * currentTransmissionSize),
                                           datapoints.end() - ((transmissions - (i + 1)) * currentTransmissionSize));
    // Transmit the collected data.
    bool transmissionWasSuccess = transmitData(datapoints);
    if (!transmissionWasSuccess) {
      // TO-DO: Decide what to do depending on transmission failure
      break;
    }
  }
  // Release resources and go to sleep
  wifi.disconnect();
  goToSleep();
}

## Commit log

2016-12-21 Fixes to make it build
    Changed fetching source from the 0.0.1 release to the latest master
    Find the Package Threads, otherwise lpthreads does not seem to link
2017-01-05 first effort to compile multiple test source files
    does not currently work, binaries are not built
2017-01-08 Adding motor mocks
2017-01-09 Revert "Adding motor mocks"
    This reverts commit 1f26d2d16a45347ecf6d00e51b20c8ad1b6347de.
2017-01-09 Revert "Revert "Adding motor mocks""
    This reverts commit d5361462667fffe49264741f93b5995256942272.
2017-01-09 More example tests and checks if sensors have been attached
2017-01-19 Pulling Arduino-Mock from forked repo that includes additional Serials
    This until the pull request is accepted
2017-01-25 Various corrections
    * Odometer attach now does not set the odometer as attached if an invalid interrupt pin is used
    * Additional attach function according to Smartcar library v. 4.1.0
    * Returns added where it was forgotten
2017-01-29 Update build script with clean flag
    The -clean or -c flags can be used to remove
    the build folder in order to force the build
    script to download everything from the beginning.
    This can be useful if the user wants to update
    the arduino_mock classes or make sure that everything
    is built from scratch.
2017-08-17 Add example for multiple sensors
2017-10-19 Move server related files into separate directory.
    Issue #2
    [main.cpp]
2017-10-23 Remove dependency to Spdlog
    * Fixes 11
    * Minor code restructure
    [main.cpp]
2017-10-26 Add initial ins-node sketch and test
    * Minor changes to cmakelists to compile
    * Added test_utils.h to include small stubs etc
    for Arduino compatibility.
    Related to #16
2017-10-29 Add gtest-gmock test framework
    Related to #15
2017-10-29 Add INS-node board prototype
    Fixes #19
    [ins_node.brd, ins_node.sch]
2017-10-29 Add decoupling capacitor
    [ins_node.brd, ins_node.sch]
2017-10-31 Separate source folders for ins-node
    * Power controller MCU and Wifi module sketches placed
    in separate folders
    * Updates tests
    * Renamed test_utils.h
    This new structure is additionally more on par with how
    Arduino IDE handles sketches (i.e. sketch_name/sketch_name.ino)
    and makes it easier to figure out which code should run where.
    Fixes #21
    [power_controller.ino, power_controller_test.cc, wifi_module.ino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]
2017-11-07 Add new REST action, Modify database schema
    * Adds a new REST url to trigger resolution of device's position
    * Simplify database table schema for device
    * Update REST API
    * Other minor changes
    * Fixes issue #27
    * Fixes issue #28
    * Affects issue #10
2017-11-10 Fix wifi module powering issues
    HW rev.1 includes:
    * 2 MOSFETs for driving the wifi module
    * 3 AAA batteries
    * Additional decoupling capacitor
    * Board restructuring as a result of new components
    Fixes #29
    [ins_node.brd, ins_node.sch]
2017-11-10 Update board renders
2017-11-11 Update battery position and orientation for consistency
    [ins_node.brd]
2017-11-14 Add initial power manager firmware
    * TO-DO: Update wifi off and on times
    * TO-DO: Implement shutdown prevention strategy
    Fixes #23
    [power_controller.ino]
2017-11-14 Add interrupts header for completeness
2017-11-14 Add interrupts stub
2017-11-15 Add prepare shutdown logic
    Now the power controller can accept a signal from the
    Wifi module to postpone the shutdown and get back to
    SLEEP_WIFI_ON state.
2017-11-15 Fix test case names for consistency
    [power_controller_test.cc]
2017-11-15 Update documentation with power modding
2017-11-19 Add lcov initial structure
    * Currently reports for ins-node
    * Missing uploading to codecov.io
    * Missing reports for server
2017-12-03 Wifi_node - prototype
2017-12-03 Fix module never going to sleep after failed connection
    [wifi_module.ino]
2017-12-03 Fix calculation of transmission size
    Also transmission size is no longer a constant in case
    we need to change it during the run due to low quality
    of communication as well as to facilitate testing.
    [wifi_module.ino]
2017-12-03 Set ON_CALL default action for millis
2017-12-03 Fix TCP request URI contents
    [wifi_module.ino]
2017-12-03 Fix retries and post request syntax
    [wifi_module.ino]
2017-12-03 Small identation fix
    Just to make everything look perfect...
    [wifi_module.ino]
2017-12-05 Fix WiFi Module power pin according to schematics
    Fixes #66
    [power_controller.ino]
2017-12-05 Fix negative voltage when Wifi module is off
    When the WiFi module was turned off, the power controller did not have
    a common ground with the wifi module, which would cause the relative
    voltage (from the wifi module's perspective) to be negative. This would
    strangely result in a constant low voltage of around 1-1.5 volts being
    present at the VCC and GND pins of the WiFi module. This resulted in
    weird behavior and overall needlessly higher power consumption.
    The fix involves the PB0 pin being set to INPUT so to avoid this noise
    on the Wifi module's side. Whenever we want to transmit a pulse through
    the PB0 pin, we set it as OUTPUT (then the WiFi module is ON so there is
    no problem) and when w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
    [power_controller.ino, power_controller_test.cc]
2017-12-05 Add pulldown resistor for MOSFETs base
    Add a pulldown resistor for the MOSFET trigger pins so to make sure
    that we have a clean signal that only activates the Wifi module
    when we want.
    This change constitutes HW Rev. 2
    Fixes #71
    [ins_node.brd, ins_node.sch]
2017-12-22 Execute GET requests for specified node on press
    On button press a GET request is sent to the local Python + Flask
    server (i.e. not the INS one) for testing and verification purposes.
    Should be later changed to the correct URI.
2017-12-30 Use ins_server URL to request device position
2017-12-31 Update installations instructions
    Use the ATtinyCore board support package instead
2018-01-01 Use multiple SSIDs for positioning
    Fixes #80
    [wifi_module.ino, wifi_module_test.cc]
2018-01-17 Handle interrupt signal for gracefull shutdown
    * Fixes #85
    [main.cpp]
2018-01-17 Use std::signal and csignal header
    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
    [main.cpp]
2018-04-22 [INS] Removed debug printf from WifiNode.c file.

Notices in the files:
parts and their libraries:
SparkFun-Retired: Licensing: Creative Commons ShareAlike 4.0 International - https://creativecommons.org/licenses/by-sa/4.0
